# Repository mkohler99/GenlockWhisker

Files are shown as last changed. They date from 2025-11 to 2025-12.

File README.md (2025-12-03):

# Genlock Whisker
Screenshot 2025-11-01 at 7 53 55 AM
Screenshot 2025-11-01 at 7 54 20 AM

# Exciting Updates!
Now with a web serial UI. Simply host the contents of the 'web' folder somewhere and open the page with Chrome (or maybe Edge? Safari does not allow web serial which makes me sad because web serial is pretty awesome) . UPDATE: Hosted here for now https://genlockwhisker.pages.dev again, this has only been tested in chrome.  TBD I *think* this requires HTTPS and you cant just open the HTML on your local machine but id love to be wrong. Anyway, the Web UI adds easier to read monitoring as well as an attempt at monitoring the statistics over time. Im trying to verify how useful ANY of these jitter measurments are and would love if anyone has......a bad genlock source that has lots of jitter to test with?
Screenshot 2025-12-03 at 4 25 40 PM

# About
The genlock whisker is an expansion module for the FUSE CATS Frame:Work 2025 NYC Pixel Kitty conference badge that allows you to turn your badge into a genlock tester. 
The device reads most types of genlock signals on an HDBNC connector and displays information about them on the badge's RGB Pixel Matrix Display.

# Current features:
- Detects Bi-Level or Tri-Level sync by displaying green for Bi-Level and blue for Tri-Level. Detects no sync or unstable sync by displaying "NO LOCK" in red
- Displays Frame rate of sync up to 3 decimal places
- Outputs sync drift statistics over USB type C serial connection

- Hardware fix for This latest code release.
Screenshot 2025-12-03 at 4 10 32 PM
Cut the indicated Pin in order to un-short the HSYNC IO Pin. Since this is actually a bug in the base Pixel Kitty Badge Board, its hard to fix perfectly since the problem can be in either place. for now, the easiest fix is to remove one header pin from the expansion module which prevents the HSYNC pin on the LMH1980 from grounding out and not being able to read. because this new version improves data gathering by detecting HSYNC lines and counting them in order to determine the signal format, this version of software will not work without the hardware mod. Screenshot 2025-12-03 at 4 22 02 PM

Because Safety is our number 1 priority, please wear safety goggles when cutting the pin as it can fly anywhere.

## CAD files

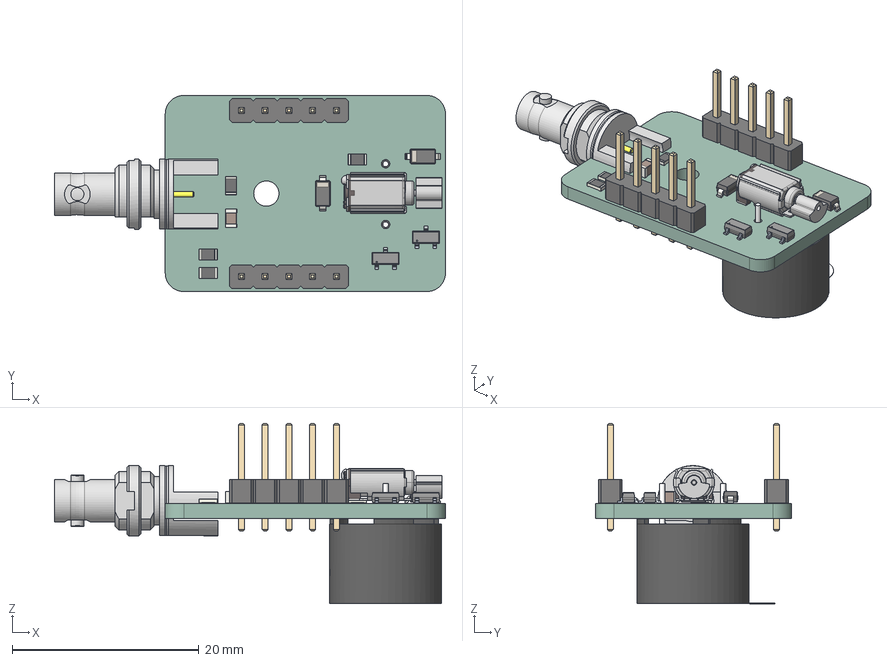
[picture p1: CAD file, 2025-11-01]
SyncWhiskerv1.STEP
41.8 x 21.0 x 19.3 mm
R_0805_2012Metric x 4
D_SOD_123 x 2
PinHeader_1x05_P254mm_Vertical x 2
C_0805_2012Metric
ASSEMBLY x 2
HD-EMB1104-SM-2
HDBNC-J-P-GN-ST-EM1
AT-1224-TWT-5V-2-R
SyncWhisker_PCB

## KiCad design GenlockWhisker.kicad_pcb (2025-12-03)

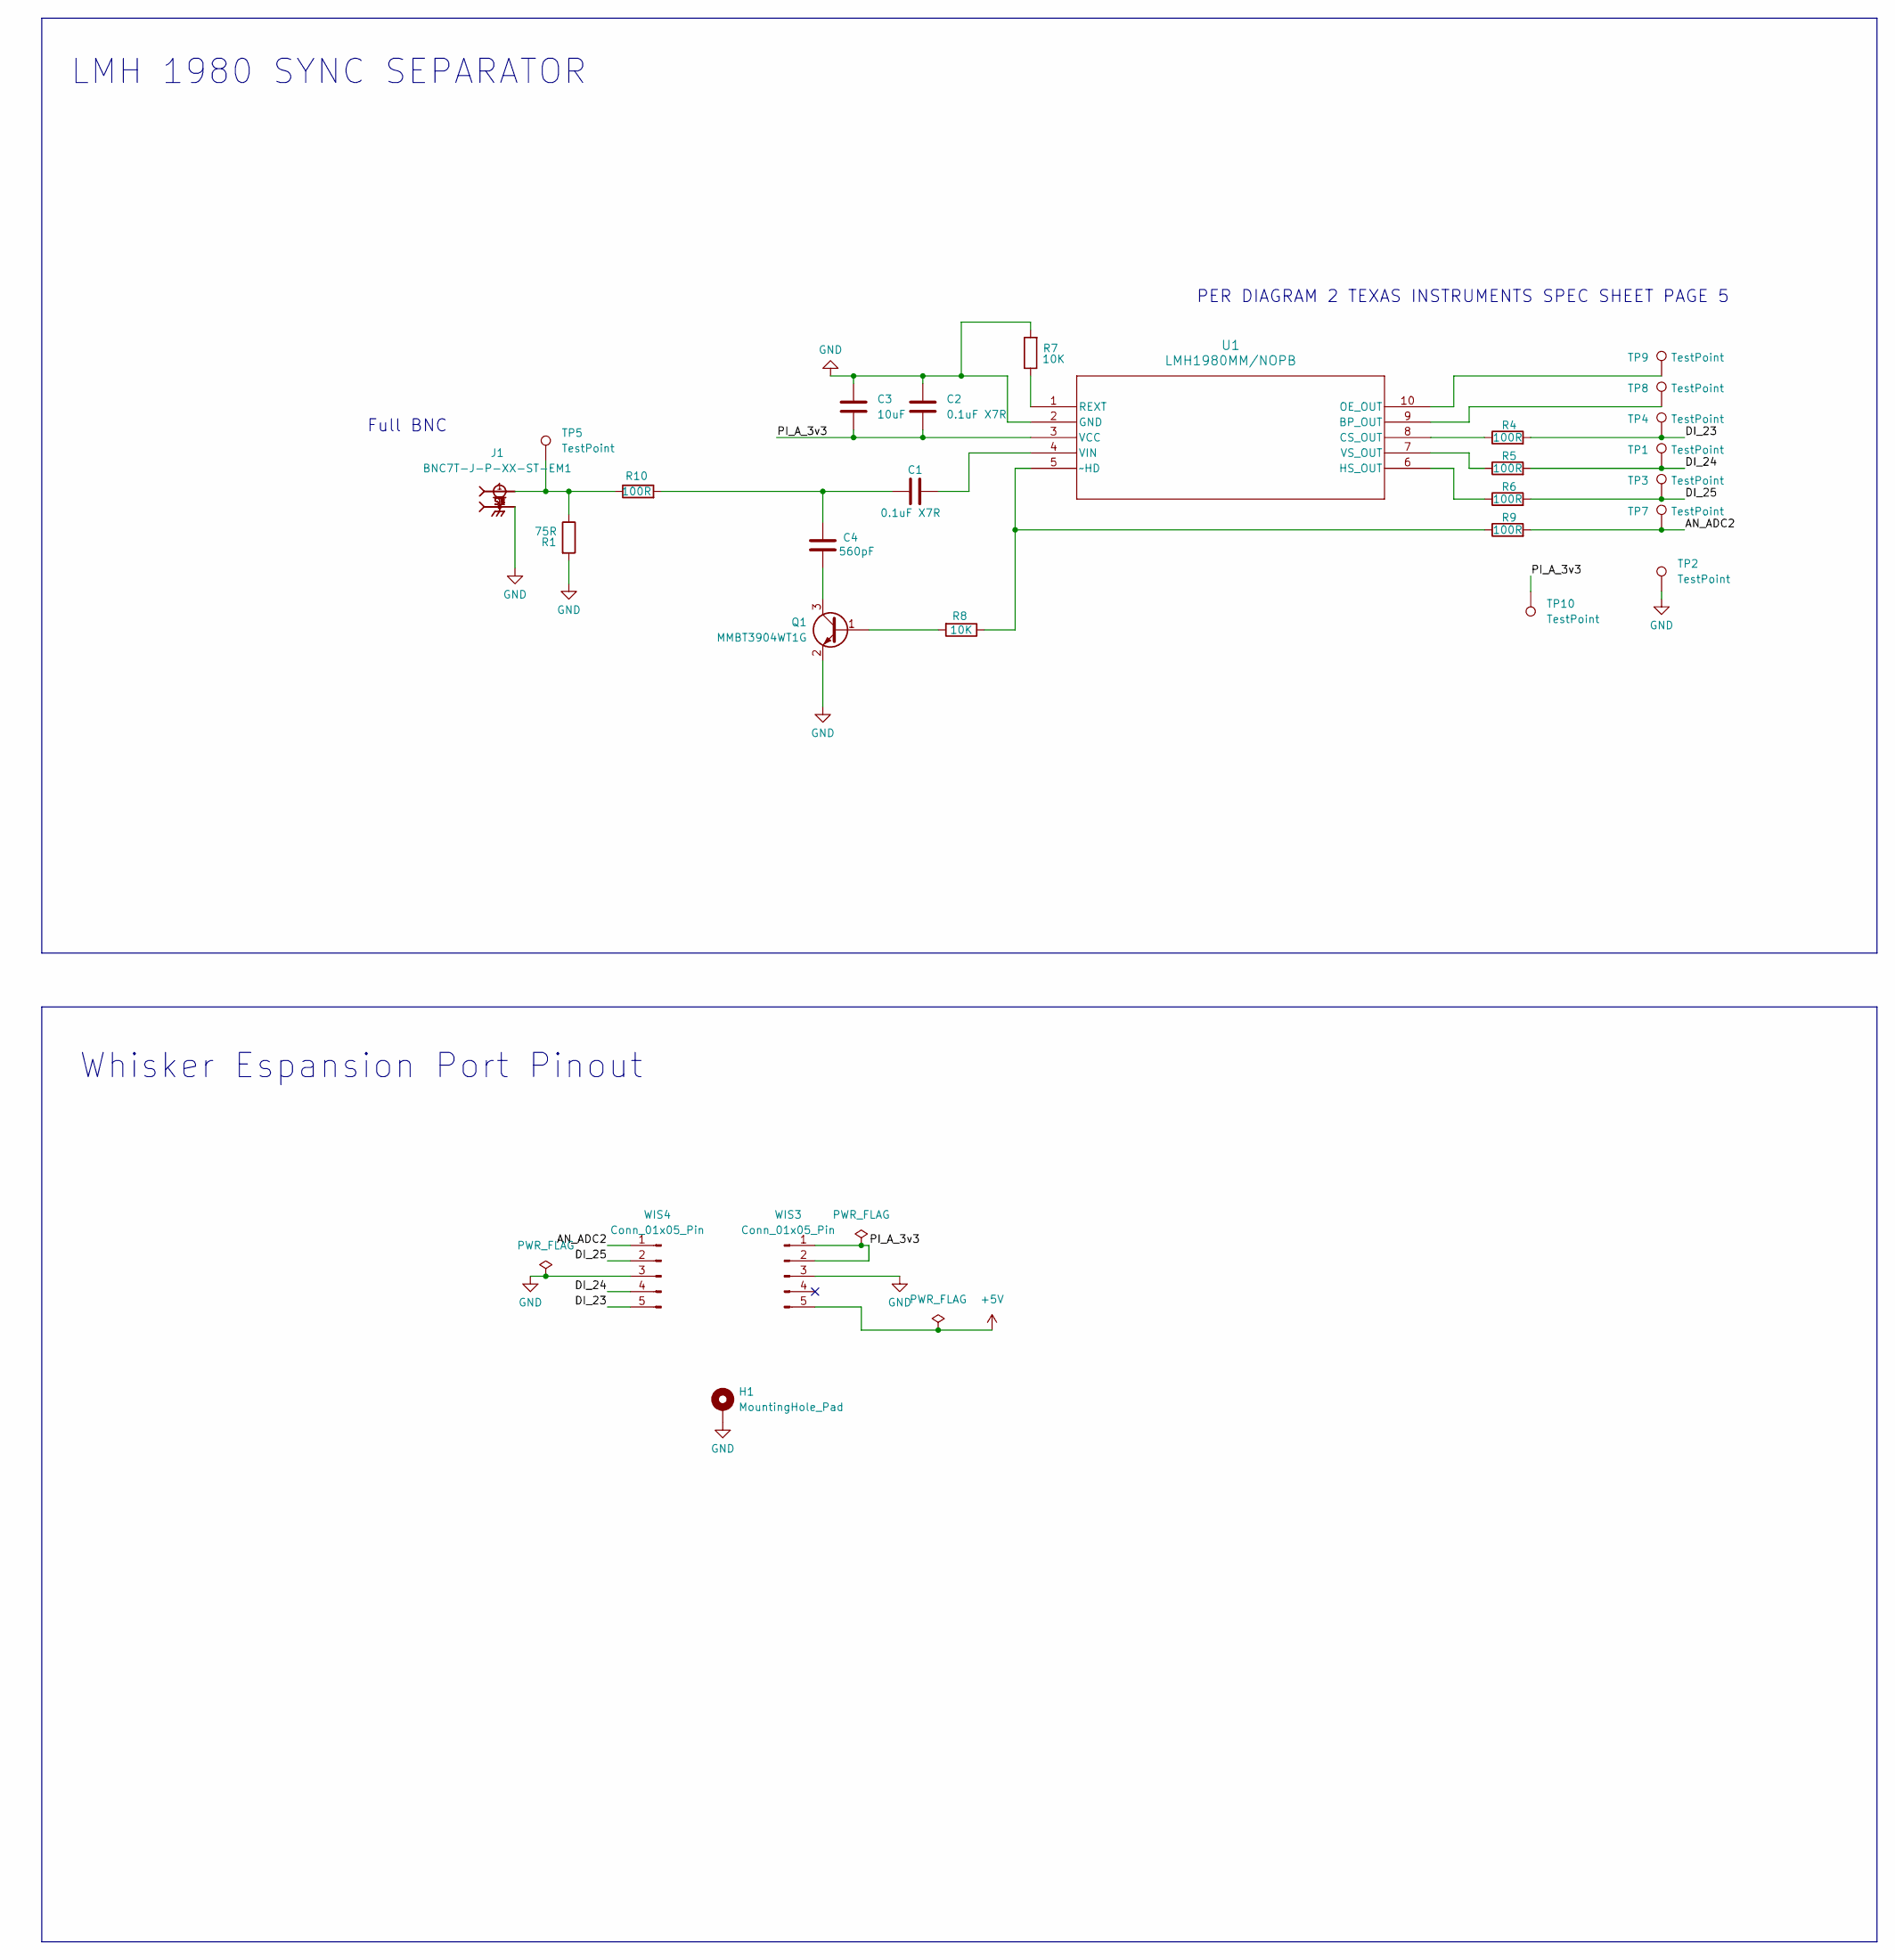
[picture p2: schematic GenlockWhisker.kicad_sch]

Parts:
C1, C2: 0.1uF X7R; C_0603_1608Metric; LCSC C14663
C3: 10uF; C_0603_1608Metric; LCSC C19702
C4: 560pF; C_0603_1608Metric; LCSC C1627
H1: MountingHole_Pad; MountingHole_2.7mm_M2.5_DIN965_Pad; LCSC DNP
J1: BNC7T-J-P-XX-ST-EM1; SAMTEC_BNC7T-J-P-XX-ST-EM1D; PARTREV E; LCSC C3173636
Q1: MMBT3904WT1G; SOT-23; LCSC C58011
R1: 75R; R_0603_1608Metric; LCSC C4275
R4, R5, R6, R9, R10: 100R; R_0603_1608Metric; LCSC C22775
R7, R8: 10K; R_0603_1608Metric; LCSC C21190
TP1, TP2, TP3, TP4, TP5, TP7, TP8, TP9, TP10: TestPoint; TestPoint_Pad_1.5x1.5mm; LCSC DNP
U1: LMH1980MM/NOPB; MUB10A; LCSC C189203
WIS3, WIS4: Conn_01x05_Pin; PinHeader_1x05_P2.54mm_Vertical; LCSC DNP

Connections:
+5V: WIS3.5
/AN_ADC2: R9.2, TP7.1, WIS4.1
/DI_23: R4.2, TP4.1, WIS4.5
/DI_24: R5.2, TP1.1, WIS4.4
/DI_25: R6.2, TP3.1, WIS4.2
/PI_A_3v3: C2.1, C3.1, TP10.1, U1.3 (VCC), WIS3.1, WIS3.2
GND: C2.2, C3.2, H1.1, J1.S1, J1.S2, J1.S3, J1.S4, Q1.2 (E), R1.2, R7.2, TP2.1, U1.2 (GND), WIS3.3, WIS4.3
unnamed: C1.1, C4.2, R10.2
unnamed: J1.1, R1.1, R10.1, TP5.1
unnamed: Q1.1 (B), R8.2
unnamed: C4.1, Q1.3 (C)
unnamed: TP8.1, U1.9 (BP_OUT)
unnamed: R4.1, U1.8 (CS_OUT)
unnamed: R6.1, U1.6 (HS_OUT)
unnamed: TP9.1, U1.10 (OE_OUT)
unnamed: R7.1, U1.1 (REXT)
unnamed: C1.2, U1.4 (VIN)
unnamed: R5.1, U1.7 (VS_OUT)
unnamed: R8.1, R9.1, U1.5 (~HD)

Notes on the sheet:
Full BNC
PER DIAGRAM 2 TEXAS INSTRUMENTS SPEC SHEET PAGE 5
LMH 1980 SYNC SEPARATOR
Whisker Espansion Port Pinout

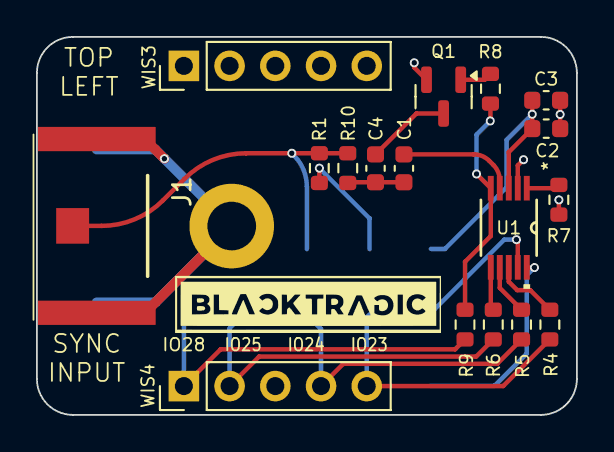
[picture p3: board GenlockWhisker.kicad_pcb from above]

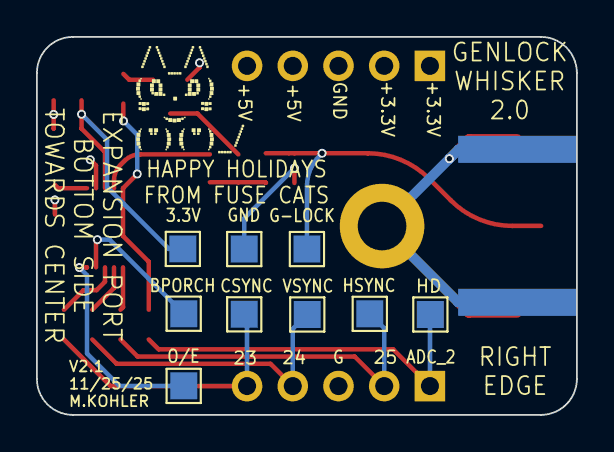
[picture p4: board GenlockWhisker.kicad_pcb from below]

Board: 4 copper layers, 30.0 x 21.0 mm, 27 parts (9 on the bottom side), 18 nets.

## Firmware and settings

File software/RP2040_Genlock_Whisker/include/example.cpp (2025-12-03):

// ======================= main.cpp (RP2040 badge) =======================
#include <Arduino.h>
#include <FastLED.h>
#include <FastLED_NeoMatrix.h>
#include <Adafruit_GFX.h>
#include <IRremote.hpp>
#include <LittleFS.h>
#include <ArduinoJson.h>

extern "C" {
  #include "hardware/watchdog.h"
}

#include "hardware/vreg.h"


// project headers you already have
#include "config.hpp"          // BadgeConfig CFG; loadConfig/saveConfig
#include "serial_cmds.hpp"     // void handleSerial();
#include "protocol.h"          // just the op codes if you keep them
#include "charms565.hpp"
#include "scene_nyan.hpp"
#include "scene_fuse.hpp"
#include "scene_kitty.hpp"
#include "scene_volt.hpp"
#include "scene_hit.hpp"
#include "scene_hitbars.hpp"
#include "scene_tx.hpp"
//#include "scenes.hpp"

//#define SCORE_SNIFFER
//#define LOUD_SERIAL

// ---- Sleep/Wake ----
#ifndef SCORE_SNIFFER
  #ifndef AUTO_SLEEP_MINUTES_DEFAULT
  #define AUTO_SLEEP_MINUTES_DEFAULT 15   // auto-sleep after 30 min of inactivity
  #endif
#endif


#ifdef SCORE_SNIFFER
  #ifndef AUTO_SLEEP_MINUTES_DEFAULT
  #define AUTO_SLEEP_MINUTES_DEFAULT 60   // auto-sleep after 30 min of inactivity
  #endif
#endif


static uint32_t btnLastMs = 0;
static bool prevB1 = true, prevB2 = true, prevB3 = true;

const char BUILD_DATE[] = __DATE__;
const char BUILD_TIME[] = __TIME__;

CRGB leds[NUM_LEDS];

// --- Fast blit: RGB565 (PROGMEM) -> FastLED CRGB in-place ---
static inline void blit565ToLeds(const uint16_t *frame565) {
  for (uint16_t i = 0; i < SCN_PIX; ++i) {
    uint16_t p = pgm_read_word(&frame565[i]);     // read from flash
    // unpack 5/6/5 to 8/8/8
    uint8_t r = ((p >> 11) & 0x1F) * 255 / 31;
    uint8_t g = ((p >> 5)  & 0x3F) * 255 / 63;
    uint8_t b = ( p        & 0x1F) * 255 / 31;
    leds[i] = CRGB(r, g, b);
  }
}

// ----- Fancy text effects -----
enum TextEffect : uint8_t { EFFECT_SOLID=0, EFFECT_RAINBOW=1, EFFECT_FIRE=2, EFFECT_GLITCH=3, EFFECT_ICE=4, EFFECT_MATRIX=5, EFFECT_FIREWORK=6, EFFECT_CHEVRON=7, EFFECT_BUGS=8, };
static TextEffect currentTextEffect = EFFECT_SOLID;
static uint8_t numberOfEffects = 9;

// params/state used by effects
static CRGB textColor = CRGB(255,255,255);  // used by SOLID
static uint8_t rainbowHue = 0;              // used by RAINBOW

FastLED_NeoMatrix* matrix = new FastLED_NeoMatrix(
  leds, WIDTH, HEIGHT,
  NEO_MATRIX_TOP + NEO_MATRIX_LEFT + NEO_MATRIX_COLUMNS + NEO_MATRIX_PROGRESSIVE
);

// ---------------- Config / state ----------------
BadgeConfig CFG;

// ================== Scoring state + helpers ==================
struct ScoreState {
  uint32_t score = 0;          // running total
  uint32_t hits_total = 0;     // any FIRE seen
  uint32_t fires_total = 0;    // local button-2 fires
  uint32_t sessions_woke = 0;  // WAKE events seen
  uint32_t scenes_triggered = 0;

  uint32_t rolls_5 = 0, rolls_10 = 0, rolls_20 = 0, rolls_40 = 0; // audit
} g_score;

// persistent meta for throttled saves
static bool     g_scoreDirty = false;
static uint32_t g_scoreLastSave = 0;

// Simple, stable RNG roll in [1..sides]
static uint16_t scoreRoll(uint8_t sides) {
  if (sides < 1) sides = 1;
  // randomSeed should be set in setup(); this is inclusive
  return (uint16_t)random(1, (long)sides + 1);
}

static void scoreAddInternal(uint32_t points, const char* why) {
  g_score.score += points;
  g_scoreDirty = true;
  if (why) Serial.printf("[SCORE] +%lu (%s) → %lu\n", (unsigned long)points, why, (unsigned long)g_score.score);
}

// Award “roll X”: add a random 1..X
static void scoreAwardRoll(uint8_t sides, const char* why) {
  uint16_t add = scoreRoll(sides);
  switch (sides) {
    case 5:  g_score.rolls_5++;  break;
    case 10: g_score.rolls_10++; break;
    case 20: g_score.rolls_20++; break;
    case 40: g_score.rolls_40++; break;
  }
  scoreAddInternal(add, why);
}

// Public helpers (used by serial_cmds.cpp too)
uint32_t scoreGet()            { return g_score.score; }
void     scoreSet(uint32_t v)  { g_score.score = v; g_scoreDirty = true; Serial.printf("[SCORE] SET → %lu\n", (unsigned long)v); }
void     scoreAdd(int32_t d)   { if (d >= 0) scoreAddInternal((uint32_t)d, "serial add"); else {
                                   uint32_t sub = (uint32_t)(-d);
                                   g_score.score = (g_score.score > sub) ? (g_score.score - sub) : 0;
                                   g_scoreDirty = true;
                                   Serial.printf("[SCORE] ADD %ld → %lu\n", (long)d, (unsigned long)g_score.score);
                                 } }

// Optional: persist score counters (keep raw stats for long-term download)
static bool scoreSave() {
  File f = LittleFS.open("/score.json", "w");
  if (!f) return false;
  StaticJsonDocument<384> doc;
  doc["score"]            = g_score.score;
  doc["hits_total"]       = g_score.hits_total;
  doc["fires_total"]      = g_score.fires_total;
  doc["sessions_woke"]    = g_score.sessions_woke;
  doc["scenes_triggered"] = g_score.scenes_triggered;
  doc["r5"]  = g_score.rolls_5;
  doc["r10"] = g_score.rolls_10;
  doc["r20"] = g_score.rolls_20;
  doc["r40"] = g_score.rolls_40;
  serializeJson(doc, f);
  f.close();
  g_scoreDirty = false;
  g_scoreLastSave = millis();
  return true;
}

static void scoreLoad() {
  File f = LittleFS.open("/score.json", "r");
  if (!f) return;
  StaticJsonDocument<384> doc;
  if (deserializeJson(doc, f) == DeserializationError::Ok) {
    g_score.score            = doc["score"]           | 0u;
    g_score.hits_total       = doc["hits_total"]      | 0u;
    g_score.fires_total      = doc["fires_total"]     | 0u;
    g_score.sessions_woke    = doc["sessions_woke"]   | 0u;
    g_score.scenes_triggered = doc["scenes_triggered"]| 0u;
    g_score.rolls_5  = doc["r5"]  | 0u;
    g_score.rolls_10 = doc["r10"] | 0u;
    g_score.rolls_20 = doc["r20"] | 0u;
    g_score.rolls_40 = doc["r40"] | 0u;
  }
  f.close();
}

// Call this in loop() to avoid flash spam
static void scoreMaybeAutoSave() {
  if (!g_scoreDirty) return;
  if (millis() - g_scoreLastSave >= 3000) (void)scoreSave();
}



static uint32_t g_lastScoreRespMs = 0;

static inline bool scoreThrottleOk() {
  if (SCORE_RESP_MIN_MS == 0) return true;                 // disabled
  uint32_t now = millis();
  // unsigned subtraction is rollover-safe
  if ((now - g_lastScoreRespMs) < SCORE_RESP_MIN_MS) return false;
  g_lastScoreRespMs = now;
  return true;
}

struct SleepState {
  bool     asleep = false;
  uint32_t lastActivityMs = 0;           // last time we saw activity (awake only)
  uint32_t autoTimeoutMs  = AUTO_SLEEP_MINUTES_DEFAULT * 60UL * 1000UL;
  uint8_t  savedBrightness128 = 7;      // save/restore user brightness
} g_sleep;

static inline void noteActivity() {
  if (!g_sleep.asleep) g_sleep.lastActivityMs = millis();
}

// ----- Score snapshot (for dump/restore without exposing internals)
struct ScoreSnapshot {
  uint32_t score, hits_total, fires_total, sessions_woke, scenes_triggered;
  uint32_t r5, r10, r20, r40;
};

void getScoreSnapshot(ScoreSnapshot &s) {
  s.score = g_score.score;
  s.hits_total = g_score.hits_total;
  s.fires_total = g_score.fires_total;
  s.sessions_woke = g_score.sessions_woke;
  s.scenes_triggered = g_score.scenes_triggered;
  s.r5 = g_score.rolls_5; s.r10 = g_score.rolls_10; s.r20 = g_score.rolls_20; s.r40 = g_score.rolls_40;
}

void setScoreSnapshot(const ScoreSnapshot &s) {
  g_score.score = s.score;
  g_score.hits_total = s.hits_total;
  g_score.fires_total = s.fires_total;
  g_score.sessions_woke = s.sessions_woke;
  g_score.scenes_triggered = s.scenes_triggered;
  g_score.rolls_5 = s.r5; g_score.rolls_10 = s.r10; g_score.rolls_20 = s.r20; g_score.rolls_40 = s.r40;
  g_scoreDirty = true; (void)scoreSave();
}

// Auto-sleep accessors
uint32_t getAutoSleepMinMs()        { return g_sleep.autoTimeoutMs; }
void     setAutoSleepMinMs(uint32_t ms) { g_sleep.autoTimeoutMs = ms; }


static uint16_t readBatteryMilliVoltsOnce() {
  uint32_t acc = 0;
  for (int i = 0; i < BATT_SAMPLES; i++) acc += analogRead(BATTERY_ADC_PIN);
  uint16_t raw = (uint16_t)(acc / BATT_SAMPLES);
  g_batt_raw = raw;

  // RP2040 ADC default resolution is 12-bit → 0..4095
  float v_adc  = (raw / 4095.0f) * ADC_FULL_SCALE_VREF;
  float v_batt = v_adc / BATTERY_DIVIDER_K;       // inverse of divider
  if (v_batt < 0.f)   v_batt = 0.f;
  if (v_batt > 9.9f)  v_batt = 9.9f;              // clamp to spec range

  return (uint16_t)(v_batt * 1000.0f + 0.5f);     // mV
}

static inline void lowBattUpdateFromReading(uint16_t batt_mV) {
  // Hysteresis:
  if (!g_lowBatt && batt_mV <= LOW_BATT_THRESH_MV) {
    g_lowBatt = true;
  } else if (g_lowBatt && batt_mV >= (LOW_BATT_THRESH_MV + LOW_BATT_HYST_MV)) {
    g_lowBatt = false;
  }
  digitalWrite(LOW_BATT_PIN, g_lowBatt ? LOW_BATT_ON : LOW_BATT_OFF);
}

static inline void lowBattLightUpdate(uint16_t batt_mV) {
  const bool on = (batt_mV >= BATT_PRESENT_MIN_MV) && (batt_mV <= LOW_BATT_THRESH_MV);
  digitalWrite(LOW_BATT_PIN, on ? LOW_BATT_ON : LOW_BATT_OFF);
}

static inline void batteryPollTick() {
  uint32_t now = millis();
  if (now - g_battLastMs >= BATT_UPDATE_MS) {
    g_battLastMs = now;
    g_batt_mV = readBatteryMilliVoltsOnce();
    lowBattLightUpdate(g_batt_mV);
  }
}

static inline bool isLowBattery() { return g_lowBatt; }

// ---------------- SIRC-20 helpers ----------------
// flip 32-bit
static inline uint32_t bitrev32(uint32_t x) {
  x = ((x >> 1) & 0x55555555u) | ((x & 0x55555555u) << 1);
  x = ((x >> 2) & 0x33333333u) | ((x & 0x33333333u) << 2);
  x = ((x >> 4) & 0x0F0F0F0Fu) | ((x & 0x0F0F0F0Fu) << 4);
  x = ((x >> 8) & 0x00FF00FFu) | ((x & 0x00FF00FFu) << 8);
  x = (x >> 16) | (x << 16);
  return x;
}
// Take IRremote's MSB-first raw32, return our LSB-first 20-bit word (right-aligned)
static inline uint32_t sirc20FlipToLSB(uint32_t raw32) {
  return bitrev32(raw32) >> (32 - 20);
}
// Unpack: [0..5]=op(6), [6..14]=attacker(9), [15..19]=hi5(5)
static inline void sirc20Unpack(uint32_t wLSB, uint8_t &op, uint16_t &att, uint8_t &hi5) {
  op  =  wLSB        & 0x3F;
  att = (wLSB >> 6)  & 0x1FF;
  hi5 = (wLSB >> 15) & 0x1F;
}
// For value-style ops (14-bit)
static inline uint16_t sirc20Value14(uint32_t wLSB) {
  uint16_t low9 = (wLSB >> 6) & 0x1FF;
  uint16_t hi5  = (wLSB >> 15) & 0x1F;
  return (hi5 << 9) | low9;
}


// Pack our 20-bit Sony word (LSB-first on the wire):
// [0..5]=op, [6..14]=attacker(9b), [15..19]=charm(5b)
static inline uint32_t sirc20Pack(uint8_t op, uint16_t attacker, uint8_t charm) {
  return (uint32_t(op & 0x3F))
       | (uint32_t(attacker & 0x1FF) << 6)
       | (uint32_t(charm & 0x1F) << 15);
}

static void sendSirc20(uint32_t word, const char* tag = nullptr) {
#ifdef IR_TX_PIN
  if (tag) Serial.printf("[IRTX] %s SIRC20=0x%05lX\n", tag, (unsigned long)word);
  else     Serial.printf("[IRTX] SIRC20=0x%05lX\n", (unsigned long)word);
  // 20-bit Sony (library sends LSB-first as needed)
  IrSender.sendSony(word, 20);
#else
  (void)word; (void)tag;
  Serial.println("[IRTX] (no IR_TX_PIN) Fire pressed — anim only");
#endif
}

// Convenience: fire with our own CFG.id and charm (0..31; 0 = no unlock)
static void sendFireBadge(uint8_t charm = 0) {
        IrReceiver.disableIRIn(); 

  uint32_t w = sirc20Pack(/*op=*/0x00, /*attacker=*/CFG.id, /*charm=*/(CFG.userCharmId & 31));
  sendSirc20(w, "FIRE");
  delay(30);
        IrReceiver.enableIRIn(); 

}

// Respond to a SCORE_REQUEST by sending 3 frames: SCORE0/1/2

static void sendScoreTriplet(uint16_t myId, uint16_t score15) {
  // split 15-bit score into 3×5b chunks
  uint8_t p0 =  score15        & 0x1F; // [4:0]
  uint8_t p1 = (score15 >> 5)  & 0x1F; // [9:5]
  uint8_t p2 = (score15 >> 10) & 0x1F; // [14:10]

  // Add small randomized/backoff delay to reduce collisions across badges
  // (also bias by ID to spread even more)
  uint16_t jitter = 10 + (myId & 0x07) * 5 + (uint16_t)random(0, 15);
  delay(jitter);

  const uint16_t interPartMs  = 14;  // gap between 0→1 and 1→2
  const uint16_t interGroupMs = 28;  // gap between repeat groups
  const uint8_t  groups       = 2;   // send triplet twice

  for (uint8_t g = 0; g < groups; ++g) {
    IrSender.sendSony(sirc20Pack(0x07, myId, p0), 20); // SCORE0
    delay(interPartMs);
    IrSender.sendSony(sirc20Pack(0x08, myId, p1), 20); // SCORE1
    delay(interPartMs);
    IrSender.sendSony(sirc20Pack(0x09, myId, p2), 20); // SCORE2
    delay(interGroupMs);
  }
}

// Pack an op with a 14-bit payload (used by SPECIAL_SCENE, etc.)
static inline uint32_t sirc20Value(uint8_t op, uint16_t value14) {
  uint16_t low9 = (value14 & 0x01FF);
  uint8_t  hi5  = (value14 >> 9) & 0x1F;
  return (uint32_t(op & 0x3F))
       | (uint32_t(low9) << 6)
       | (uint32_t(hi5)  << 15);
}


static void playSceneById(uint8_t sid);

#ifdef SCORE_SNIFFER
  #include "uart_link.hpp"
  // ================= Opcodes =================
  static constexpr uint8_t OP_FIRE          = 0x00;
  static constexpr uint8_t OP_SLEEP         = 0x01;
  static constexpr uint8_t OP_WAKE          = 0x02;
  static constexpr uint8_t OP_SET_BRIGHT    = 0x03;
  static constexpr uint8_t OP_SHOW_MESSAGE  = 0x04;
  static constexpr uint8_t OP_SPECIAL_SCENE = 0x05;

  static constexpr uint8_t OP_SCORE_REQUEST = 0x06; // TX by this sketch (periodic)
  static constexpr uint8_t OP_SCORE0        = 0x07; // RX payload = score[4:0]
  static constexpr uint8_t OP_SCORE1        = 0x08; // RX payload = score[9:5]
  static constexpr uint8_t OP_SCORE2        = 0x09; // RX payload = score[14:10]

  // ================= Request pacing / housekeeping =================
  static uint16_t g_reqPeriodMs = 1500; // changeable via UART {"t":"set","req_ms":...}
  static constexpr uint8_t  IR_REPEATS    = 0;
  static constexpr uint16_t IR_GAP_MS     = 8;
  static constexpr uint16_t REQUESTER_ID  = 0;     // attacker/ID field for the request

  static uint32_t g_lastReqMs = 0;

  // ================= Unique badges seen (for heartbeat) =================
  // 512 badges -> 512 bits
  static uint32_t g_seenBits[16] = {0}; // 16 * 32 = 512
  static inline void seenAdd(uint16_t id) {
    if (id >= 512) return;
    g_seenBits[id >> 5] |= (1u << (id & 31));
  }
  static inline uint16_t uniqueBadgeCount() {
    uint16_t n = 0;
    for (int i=0;i<16;i++) n += __builtin_popcount(g_seenBits[i]);
    return n;
  }

    // ================= Triplet assembler =================
  struct Triplet {
    uint16_t id;              // 0..511, 0xFFFF => free
    uint8_t  have;            // bit0=part0, bit1=part1, bit2=part2
    uint16_t score;           // 15-bit assembled
    uint16_t lastComplete;    // last printed score for dedupe
    uint32_t t0;              // last activity
    uint32_t lastPrintMs;     // last full print time
  };

  static constexpr uint8_t  MAX_TRACK = 32;
  static constexpr uint32_t TTL_MS    = 1500; // clear partial if idle > 1.5s
  static constexpr uint32_t DEDUPE_MS = 600;  // suppress duplicate completes

  static Triplet g_trips[MAX_TRACK];

  static void tripsInit() {
    for (auto &t : g_trips) {
      t.id = 0xFFFF; t.have = 0; t.score = 0; t.lastComplete = 0; t.t0 = 0; t.lastPrintMs = 0;
    }
  }
  static Triplet* tripsFind(uint16_t id) {
    for (auto &t : g_trips) if (t.id == id) return &t;
    return nullptr;
  }
  static Triplet* tripsAlloc(uint16_t id) {
    for (auto &t : g_trips) if (t.id == 0xFFFF) {
      t.id = id; t.have = 0; t.score = 0; t.t0 = millis(); t.lastComplete=0; t.lastPrintMs=0;
      return &t;
    }
    // evict oldest or stale
    uint32_t now = millis();
    Triplet* oldest = &g_trips[0];
    for (auto &t : g_trips) {
      if (t.id != 0xFFFF && (now - t.t0) > TTL_MS) {
        t.id = id; t.have = 0; t.score = 0; t.t0 = now; t.lastComplete=0; t.lastPrintMs=0;
        return &t;
      }
      if (t.t0 < oldest->t0) oldest = &t;
    }
    oldest->id = id; oldest->have = 0; oldest->score = 0; oldest->t0 = now; oldest->lastComplete=0; oldest->lastPrintMs=0;
    return oldest;
  }
  static void tripsHousekeep() {
    uint32_t now = millis();
    for (auto &t : g_trips) {
      if (t.id != 0xFFFF && (now - t.t0) > TTL_MS) {
        t.id = 0xFFFF; t.have = 0; t.score = 0; t.lastComplete = 0; t.lastPrintMs = 0;
      }
    }
  }

  static void processScorePart(uint16_t id, uint8_t which /*0,1,2*/, uint8_t payload5) {
    Triplet* tr = tripsFind(id);
    if (!tr) tr = tripsAlloc(id);
    tr->t0 = millis();
    seenAdd(id); // track unique for heartbeat

    // Insert bits into 15-bit score: [4:0], [9:5], [14:10]
    switch (which) {
      case 0: tr->score = (tr->score & ~0x001F) | (payload5 & 0x1F);         tr->have |= 0x01; break;
      case 1: tr->score = (tr->score & ~0x03E0) | ((payload5 & 0x1F) << 5);  tr->have |= 0x02; break;
      case 2: tr->score = (tr->score & ~0x7C00) | ((payload5 & 0x1F) <<10);  tr->have |= 0x04; break;
      default: return;
    }

    Serial.printf("[SCORE] part=%u id=%u bits=0x%02X have=0x%02X\n",
                  which, id, payload5 & 0x1F, tr->have);

    // Notify ESP about the part we just received
    UartLink::sendPart(id, which, (payload5 & 0x1F), tr->have);

    if (tr->have == 0x07) {
      uint32_t now = millis();
      if (tr->lastComplete == tr->score && (now - tr->lastPrintMs) < DEDUPE_MS) {
        tr->have = 0; // suppress duplicate final print from repeats
        return;
      }
      tr->lastComplete = tr->score;
      tr->lastPrintMs  = now;
      if (tr->id < 500){
        Serial.printf("[SCORE] COMPLETE id=%u score=%u\n", tr->id, tr->score);
        //blink some stuff here
        playSceneById(SCENE_TX_ID);
            noteActivity();

        UartLink::sendScore(tr->id, tr->score, 3);
      }
      else 
      {Serial.println("Score Ignored, Control Badge");}

      tr->have = 0; // ready for next triplet
    }
  }


  static void tickRequestTx() {
    //IrReceiver.disableIRIn(); 
  
    uint32_t now = millis();
    if (now - g_lastReqMs < g_reqPeriodMs) return;
    g_lastReqMs = now;

    uint32_t w = sirc20Pack(OP_SCORE_REQUEST, REQUESTER_ID, 0);
    sendSirc20(w, "SCORE_REQUEST");

    //IrReceiver.enableIRIn(); 
  }
#endif

//prototyle for drawcharm565
static void drawCharm565(uint8_t id, int16_t x, int16_t y);


// exact 0..128 -> 0..255
uint8_t map128to255(uint8_t v){ 
  if (v > 20){return (uint16_t(20));}
  else{return (uint16_t(v)*255u)/128u;} 

}


static inline uint16_t badgeColor565() {
  uint8_t r=(CFG.colorRGB>>16)&0xFF, g=(CFG.colorRGB>>8)&0xFF, b=CFG.colorRGB&0xFF;
  return matrix->Color(r,g,b);
}

// ---- Unique attacker set (512 bits) + persistence ----
static uint32_t g_attackerBits[16]; // 16 * 32 = 512 ids

static inline bool statsAddAttacker(uint16_t id) {
  if (id >= 512) return false;
  uint8_t w = id >> 5;                 // 0..15
  uint32_t m = 1u << (id & 31);
  bool was = (g_attackerBits[w] & m);
  g_attackerBits[w] |= m;
  if (!was) {
    // persist lazily; cheap binary dump
    File f = LittleFS.open("/attackers.bin", "w");
    if (f) { f.write((const uint8_t*)g_attackerBits, sizeof(g_attackerBits)); f.close(); }
  }
  return !was;
}

uint16_t statsUniqueCount() {
  uint16_t n = 0;
  for (int i=0;i<16;i++) n += __builtin_popcount(g_attackerBits[i]);
  return n;
}

void statsLoadAttackers() {
  memset(g_attackerBits, 0, sizeof(g_attackerBits));
  File f = LittleFS.open("/attackers.bin", "r");
  if (f) { f.read((uint8_t*)g_attackerBits, sizeof(g_attackerBits)); f.close(); }
}


// ---------------- Simple message system ----------------
static const uint8_t CHAR_W = 6;     // 5x7 font + 1px gap
static const uint16_t SCROLL_MS = 80;

static String buildIdleLine();
static String resolveMessageText(uint8_t id);


static String resolveMessageText(uint8_t id) {
  //if (id == 0) return buildIdleLine();
  switch (id) {
    case 1: return "Fuse CATS: Michael Kohler, Andy Babin, and Ryan Middlemiss 2025";
    case 2: return "Framework New York 2025";
    case 3: return "Share and Enjoy";
    case 4: return "Next session starts in 5 min";
    case 5: return "Next session starts in 10 min";
    default: return String("MSG ") + id;
  }
}

static String buildIdleLine() {
  String s = CFG.name.length() ? CFG.name : "Badge";
  if (CFG.sleepDisabled) {                 // still append Message 2
    String m2 = resolveMessageText(2);     // “Share and enjoy”
    if (m2.length()) { s += "  "; s += m2; }
  }
  return s;
}
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
void loop() {
  watchdog_update();  
  handleIR();
  handleButtons();

  if (g_sleep.asleep) {
    // Do not render anything while asleep; still process IR/buttons/serial below.
    sleepBreathTick();
  } else {
    if (g_scene.active) {
      sceneTick();
    } else if (g_fire.active) {
      fireAnimRender();
    } else if (g_stats.active) {
      statsTick();
    } else {
      renderScrollTick();
    }
  }
  sceneQueueTick();
  batteryPollTick();

  handleSerial(); 
  // If sleep is disabled, pin runtime brightness to 20 (0..128 scale), without persisting.
  if (CFG.sleepDisabled && CFG.brightness != 3) {
    CFG.brightness = 13;                            // runtime only
    FastLED.setBrightness(map128to255(13));
    FastLED.show();
  }

  // --- Auto-sleep when awake (gated by persistent CFG.sleepDisabled) ---
  if (!g_sleep.asleep) {
    if (!CFG.sleepDisabled &&
        g_sleep.autoTimeoutMs &&
        (uint32_t)(millis() - g_sleep.lastActivityMs) >= g_sleep.autoTimeoutMs) {
      sleepEnter();
    }
  }

  scoreMaybeAutoSave();  // throttle persistent writes

#ifdef SCORE_SNIFFER
  tickRequestTx();
  tripsHousekeep();
  UartLink::poll();

  // Heartbeat every 3 seconds
  static uint32_t tHb = 0;
  if ((uint32_t)(millis() - tHb) > 3000) {
    UartLink::sendHeartbeat(g_reqPeriodMs, uniqueBadgeCount());
    tHb = millis();
  }
#endif


}
// ======================================================================
